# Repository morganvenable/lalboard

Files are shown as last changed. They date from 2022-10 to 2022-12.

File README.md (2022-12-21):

##### lalboard - A 3D-printed keyboard inspired by the DataHand.



## Links

[More Images](https://github.com/JesusFreke/lalboard/wiki/Images)

[120 WPM Typing Demo](https://www.youtube.com/watch?v=oMhOIgrdeE0)

[V2 Project Logs (hackaday.io)](http://lalboard.com)

Online viewer for cluster assemblies:

- [finger](https://a360.co/3vxlLLL)
- [left thumb](https://a360.co/3c63TzE)
- [right thumb](https://a360.co/3c6tvws)

## Project Details

I am a long-time user of a DataHand keyboard. With the scarcity and rising cost of second hand
DataHands these days, I wanted to ensure that I always had access to a DataHand-like keyboard. And
so this project was born.

The overall functionality of the lalboard is obviously heavily based on the DataHand, but I designed
all of the specific key mechanisms, etc. from scratch, to be printable on a normal hobby-level
FDM printer.

With my DataHand, I never felt like I could get the keys positioned *quite right* for my hand. So
one of my primary focuses with the lalboard was adjustability. Each key cluster can be independently
adjusted in all 6 degrees of freedom to some extent.

Most parts need to be printed in a very opaque PLA, but there are a few parts that don't work well
in PLA which should be printed in polycarbonate or similar material, for its strength and heat
resistance.

##### Key Mechanisms

All keys use a pair of magnets to provide the clickiness and key return force, and an IR LED and
phototransistor for detecting a keypress. They are all held in place only with magnets, so they
are easily removable for cleaning, etc.

The feel/clickiness of the keys was another focus area. I tried to get them to feel as similar to
those on a DataHand as possible. They require roughly the same amount of force, and have that same
unique clicky feel due to the magnetic holding force.

##### Adjustability

The key clusters have a trio of standoffs that are designed to be mounted onto a steel sheet with
magnets. Each standoff has an adjustable height, and is mounted to the key cluster via a
ball socket. This provides a limited 6 degrees of freedom in adjusting the angle and position of
each key cluster, in order to get it perfectly positioned for your hands.

##### Fit

Fit is hard and individual.  Additionally, if you're not already a DH user, you'll be adjusting to the new mechanism, layout and typing style, too.  Doing all of this simultaneously can lead to overly fussy adjustment -- sometimes you just have to settle in.

Recommendations for fit:
Your hand should feel relaxed, and your palms should be supported beneath the center of the palm beneath the middle finger, at the minimum.  A palmrest that is too wide will cause discomfort in the outside of the hand, as the base of the pinky really wants to be able to curl around the palmrest a bit.

The palmrests should feel a little crazy tall compared to any other keyboard -- the motions are so small that you can get way more support from the palmrests on a lalboard/datahand.  That said, there are users who use the DH without palmrests at all, so it's a matter of experimentation and preference.  Start with rests, for sure because the relaxation of your hands from the high force, big motion world of traditional keyboards will take some time.

Finger position should be gently curved, maybe 45 degrees from vertical on the final knuckle to the keys -- too much curvature will cause a feeling of being cramped, with many unintentional N keypresses.  Too little will make you strain to hit the N keys.  You want to be able to relax and let your fingers extend naturally.

##### Electronics

As of V2, the lalboard uses standard PCBAs with a mix of SMT and through hole components.  The LEDs and phototransistors (PTs) are vertically mounted and side-firing, so they need to be soldered carefully to ensure they fit into the cluster body.  Once they are installed, there is little need for any additional fasteners, although a clamping screw hole is included in the design.

Each side of the keyboard uses an ESP32S2 MCU, and either can function as the USB connection to the PC.
The connections between the keys are 7 conductor JST cables which can be purchased directly on Amazon, and work fine.  If you want to make your own with nice silicone wires you can (see V1 readme), but the off-the-shelf ones do okay.

The halves are built flashed individually with separate Left and Right FW images that must each be built separately with a special command.
Noted here for convenience (assuming your device is on /dev/ttyACM0)
`SIDE=left idf.py -p /dev/ttyACM0 flash`
`SIDE=right idf.py -p /dev/ttyACM0 flash`
"SIDE" is an environment variable passed to the build system.

##### Handrest

The handrest was first molded for my wrist in plasticine clay, and then scanned in using the
[meshroom](https://github.com/alicevision/meshroom) photogrammetry software. Since they were molded
for my wrists specifically, I'm not sure how "one-size-fits-all" they are, or how comfortable they
would be for someone else to use.

##### [BOM](https://github.com/JesusFreke/lalboard/wiki/BOM)

##### [Printing tips & instructions](https://github.com/JesusFreke/lalboard/wiki/Printing-tips-&-instructions)

--------

Note: This is not an officially supported Google product.

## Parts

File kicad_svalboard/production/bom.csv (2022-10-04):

Designator | Footprint | Quantity | Value | LCSC Part #
C4 | C_0805_2012Metric_Pad1.15x1.40mm_HandSolder | 1 | .1u | C28233
J1 | JST_ZH_B7B-ZR_1x07_P1.50mm_Vertical | 1 | Conn_01x07 | C157978
J3 | JST_ZH_B7B-ZR_1x07_P1.50mm_Vertical | 1 | Conn_01x07 | C157978
J4 | JST_ZH_B7B-ZR_1x07_P1.50mm_Vertical | 1 | Conn_01x07 | C157978
J5 | JST_ZH_B7B-ZR_1x07_P1.50mm_Vertical | 1 | Conn_01x07 | C157978
J2 | JST_ZH_B7B-ZR_1x07_P1.50mm_Vertical | 1 | Conn_01x07 | C157978
J8 | JST_ZH_B7B-ZR_1x07_P1.50mm_Vertical | 1 | Conn_01x07 | C157978
D1 | LED_0805_2012Metric_Pad1.15x1.40mm_HandSolder | 1 | LED | C2297
H1 | MountingHole_3.2mm_M3_DIN965_Pad | 1 | MountingHole_Pad
H2 | MountingHole_3.2mm_M3_DIN965_Pad | 1 | MountingHole_Pad
J6 | PJ-320D | 1 | PJ-320D | C521460
U1 | ProMicro_v3.5 | 1 | ProMicro | C2874015
R11 | R_0805_2012Metric_Pad1.15x1.40mm_HandSolder | 1 | 1.5k | C4310
R12 | R_0805_2012Metric_Pad1.15x1.40mm_HandSolder | 1 | 1.5k | C4310
R13 | R_0805_2012Metric_Pad1.15x1.40mm_HandSolder | 1 | 1.5k | C4310
R10 | R_0805_2012Metric_Pad1.15x1.40mm_HandSolder | 1 | 1.5k | C4310
R14 | R_0805_2012Metric_Pad1.15x1.40mm_HandSolder | 1 | 1.5k | C4310
R3 | R_0805_2012Metric_Pad1.15x1.40mm_HandSolder | 1 | 100k | C149504
R5 | R_0805_2012Metric_Pad1.15x1.40mm_HandSolder | 1 | 2k | C17604
R8 | R_0805_2012Metric_Pad1.15x1.40mm_HandSolder | 1 | 2k | C17604
R7 | R_0805_2012Metric_Pad1.15x1.40mm_HandSolder | 1 | 2k | C17604
R9 | R_0805_2012Metric_Pad1.15x1.40mm_HandSolder | 1 | 2k | C17604
R6 | R_0805_2012Metric_Pad1.15x1.40mm_HandSolder | 1 | 2k | C17604
R4 | R_0805_2012Metric_Pad1.15x1.40mm_HandSolder | 1 | 390k | C17656
R1 | R_0805_2012Metric_Pad1.20x1.40mm_HandSolder | 1 | 5k | C352178
Q6 | SOT-23_Handsoldering | 1 | Q_NMOS_GSD | C5122029
Q4 | SOT-23_Handsoldering | 1 | Q_NPN_BEC | C23869
Q5 | SOT-23_Handsoldering | 1 | Q_NPN_BEC | C23869
Q1 | SOT-23_Handsoldering | 1 | Q_NPN_BEC | C23869
Q3 | SOT-23_Handsoldering | 1 | Q_NPN_BEC | C23869
Q2 | SOT-23_Handsoldering | 1 | Q_NPN_BEC | C23869
SW2 | SW_PUSH_6mm_H5mm | 1 | Boot | C428628
SW1 | SW_PUSH_6mm_H5mm | 1 | Reset | C428628
U5 | TSSOP-14_4.4x5mm_P0.65mm | 1 | LMV324 | C398929
U6 | TSSOP-14_4.4x5mm_P0.65mm | 1 | LMV324 | C398929

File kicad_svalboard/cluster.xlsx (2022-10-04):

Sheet: cluster
Source: | C:\Users\morga\Documents\GitHub\lalboard\kicad\cluster.sch
Date: | 2022-08-30 10:52
Tool: | Eeschema (6.0.7)
Generator: | C:\Program Files\KiCad\6.0\bin\scripting\plugins/bom_csv_grouped_by_value_with_fp.py
Component Count: | 16
Ref | Qnty | Value | Cmp name | Footprint | Description | Vendor
IR1, IR2, IR3, IR4, IR5, | 5 | IR908-7C-F | IR908-7C-F | lalboard:IR908-7C-F | 940nm Sidelooker IR LED
J1, | 1 | Conn_01x07 | Conn_01x07 | lalboard:JST_ZH_S7B-ZR_1x07_P1.50mm_Horizontal | Generic connector, single row, 01x07, script generated (kicad-library-utils/schlib/autogen/connector/)
PT1, PT2, PT3, PT4, PT5, | 5 | PT908-7B-F | PT908-7B-F | lalboard:PT908-7C-F | 940nm Sidelooker Phototransistor
R1, R2, R3, R4, R5, | 5 | 270 | R | Resistor_SMD:R_1206_3216Metric_Pad1.42x1.75mm_HandSolder | Resistor

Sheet: main_board
Source: | C:\Users\morga\Documents\GitHub\lalboard\kicad\main_board.sch
Date: | 2022-08-30 10:51
Tool: | Eeschema (6.0.7)
Generator: | C:\Program Files\KiCad\6.0\bin\scripting\plugins/bom_csv_grouped_by_value_with_fp.py
Component Count: | 56
Ref | Qnty | Value | Cmp name | Footprint | Description | Vendor
C1, C6, | 2 | 10u | C_Small | Capacitor_SMD:C_0805_2012Metric_Pad1.15x1.40mm_HandSolder | Unpolarized capacitor, small symbol
C2, C4, C5, C8, C9, | 5 | .1u | C_Small | Capacitor_SMD:C_0805_2012Metric_Pad1.15x1.40mm_HandSolder | Unpolarized capacitor, small symbol
C3, | 1 | 1u | C_Small | Capacitor_SMD:C_0805_2012Metric_Pad1.15x1.40mm_HandSolder | Unpolarized capacitor, small symbol
C7, | 1 | 4.7u | C_Small | Capacitor_SMD:C_0805_2012Metric_Pad1.15x1.40mm_HandSolder | Unpolarized capacitor, small symbol
FB1, FB2, FB3, FB4, | 4 | ACML-0805-500-T | Ferrite_Bead_Small-Device | Inductor_SMD:L_0805_2012Metric_Pad1.15x1.40mm_HandSolder
H1, H2, | 2 | MountingHole_Pad | MountingHole_Pad | MountingHole:MountingHole_3.2mm_M3_DIN965_Pad | Mounting Hole with connection
J1, J2, J3, J4, J5, J8, | 6 | Conn_01x07 | Conn_01x07 | lalboard:JST_ZH_B7B-ZR_1x07_P1.50mm_Vertical | Generic connector, single row, 01x07, script generated (kicad-library-utils/schlib/autogen/connector/)
J6, J7, | 2 | TYPE-C-31-M-12 | USB_C_Receptacle_USB2.0-Connector | Connector_USB:USB_C_Receptacle_HRO_TYPE-C-31-M-12
Q1, Q2, Q3, Q4, Q5, | 5 | Q_NPN_BEC | Q_NPN_BEC | Package_TO_SOT_SMD:SOT-23_Handsoldering | NPN transistor, base/emitter/collector
R1, R2, | 2 | 10k | R_Small | Resistor_SMD:R_0805_2012Metric_Pad1.15x1.40mm_HandSolder | Resistor, small symbol
R3, | 1 | 100k | R_Small | Resistor_SMD:R_0805_2012Metric_Pad1.15x1.40mm_HandSolder | Resistor, small symbol
R4, | 1 | 390k | R_Small | Resistor_SMD:R_0805_2012Metric_Pad1.15x1.40mm_HandSolder | Resistor, small symbol
R5, R6, R7, R8, R9, | 5 | 2k | R_Small | Resistor_SMD:R_0805_2012Metric_Pad1.15x1.40mm_HandSolder | Resistor, small symbol
R10, R11, R12, R13, R14, | 5 | 1.5k | R | Resistor_SMD:R_0805_2012Metric_Pad1.15x1.40mm_HandSolder | Resistor
R15, R16, R17, R18, | 4 | 5.1k | R_Small | Resistor_SMD:R_0805_2012Metric_Pad1.15x1.40mm_HandSolder | Resistor, small symbol
R19, R20, | 2 | 22 | R_Small | Resistor_SMD:R_0805_2012Metric_Pad1.15x1.40mm_HandSolder | Resistor, small symbol
SW1, | 1 | Reset | SW_Push | Button_Switch_THT:SW_PUSH_6mm_H5mm | Push button switch, generic, two pins
SW2, | 1 | Boot | SW_Push | Button_Switch_THT:SW_PUSH_6mm_H5mm | Push button switch, generic, two pins
U1, | 1 | esp32-s2-wroom | esp32-s2-wroom | lalboard:ESP32-S2-WROOM-handsoldering
U2, | 1 | XC6220B331MR | XC6220B331MR | Package_TO_SOT_SMD:SOT-23-5 | 1A, Low Drop-out Voltage Regulator, Fixed Output 3.3V, SOT-23-5
U3, U4, | 2 | USBLC6-2SC6 | USBLC6-2SC6 | Package_TO_SOT_SMD:SOT-23-6 | Very low capacitance ESD protection diode, 2 data-line, SOT-23-6
U5, U6, | 2 | LMV324 | LMV324 | lalboard:TSSOP-14_4.4x5mm_P0.65mm | Quad Low-Voltage Rail-to-Rail Output Operational Amplifier, SOIC-14/SSOP-14

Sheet: thumb_cluster_left
Source: | C:\Users\morga\Documents\GitHub\lalboard\kicad\thumb_cluster_left.kicad_sch
Date: | 2022-08-30 10:53
Tool: | Eeschema (6.0.7)
Generator: | C:\Program Files\KiCad\6.0\bin\scripting\plugins/bom_csv_grouped_by_value_with_fp.py
Component Count: | 18
Ref | Qnty | Value | Cmp name | Footprint | Description | Vendor
H1, H2, | 2 | MountingHole_Pad | MountingHole_Pad | MountingHole:MountingHole_3.2mm_M3_Pad | Mounting Hole with connection
IR1, IR2, IR3, IR4, IR5, | 5 | IR908-7C-F | IR908-7C-F | lalboard:IR908-7C-F | 940nm Sidelooker IR LED
J1, | 1 | Conn_01x07 | Conn_01x07 | lalboard:JST_ZH_B7B-ZR_1x07_P1.50mm_Vertical | Generic connector, single row, 01x07, script generated (kicad-library-utils/schlib/autogen/connector/)
PT1, PT2, PT3, PT4, PT5, | 5 | PT908-7B-F | PT908-7B-F | lalboard:PT908-7C-F | 940nm Sidelooker Phototransistor
R1, | 1 | 56 | R | Resistor_SMD:R_1206_3216Metric_Pad1.42x1.75mm_HandSolder | Resistor
R2, | 1 | 100 | R | Resistor_SMD:R_1206_3216Metric_Pad1.42x1.75mm_HandSolder | Resistor
R3, | 1 | 120 | R | Resistor_SMD:R_1206_3216Metric_Pad1.42x1.75mm_HandSolder | Resistor
R4, | 1 | 180 | R | Resistor_SMD:R_1206_3216Metric_Pad1.42x1.75mm_HandSolder | Resistor
R5, | 1 | 150 | R | Resistor_SMD:R_1206_3216Metric_Pad1.42x1.75mm_HandSolder | Resistor

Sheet: thumb_cluster_right
Source: | C:\Users\morga\Documents\GitHub\lalboard\kicad\thumb_cluster_right.kicad_sch
Date: | 2022-08-30 10:54
Tool: | Eeschema (6.0.7)
Generator: | C:\Program Files\KiCad\6.0\bin\scripting\plugins/bom_csv_grouped_by_value_with_fp.py
Component Count: | 18
Ref | Qnty | Value | Cmp name | Footprint | Description | Vendor
H1, H2, | 2 | MountingHole_Pad | MountingHole_Pad | MountingHole:MountingHole_3.2mm_M3_Pad | Mounting Hole with connection
IR1, IR2, IR3, IR4, IR5, | 5 | IR908-7C-F | IR908-7C-F | lalboard:IR908-7C-F | 940nm Sidelooker IR LED
J1, | 1 | Conn_01x07 | Conn_01x07 | lalboard:JST_ZH_B7B-ZR_1x07_P1.50mm_Vertical | Generic connector, single row, 01x07, script generated (kicad-library-utils/schlib/autogen/connector/)
PT1, PT2, PT3, PT4, PT5, | 5 | PT908-7B-F | PT908-7B-F | lalboard:PT908-7C-F | 940nm Sidelooker Phototransistor
R1, | 1 | 56 | R | Resistor_SMD:R_1206_3216Metric_Pad1.42x1.75mm_HandSolder | Resistor
R2, | 1 | 100 | R | Resistor_SMD:R_1206_3216Metric_Pad1.42x1.75mm_HandSolder | Resistor
R3, | 1 | 120 | R | Resistor_SMD:R_1206_3216Metric_Pad1.42x1.75mm_HandSolder | Resistor
R4, | 1 | 180 | R | Resistor_SMD:R_1206_3216Metric_Pad1.42x1.75mm_HandSolder | Resistor
R5, | 1 | 150 | R | Resistor_SMD:R_1206_3216Metric_Pad1.42x1.75mm_HandSolder | Resistor

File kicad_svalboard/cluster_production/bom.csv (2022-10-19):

Designator | Footprint | Quantity | Value | LCSC Part #
J1 | FH34SRJ8S05SH50 | 1 | Conn_01x07
Q2 | PT12-21B | 1 | PT12-21B | C264383
Q5 | PT12-21B | 1 | PT12-21B | C264383
D3 | IR12-21C | 1 | IR12-21C | C53672
D1 | IR12-21C | 1 | IR12-21C | C53672
Q4 | PT12-21B | 1 | PT12-21B | C264383
D4 | IR12-21C | 1 | IR12-21C | C53672
Q3 | PT12-21B | 1 | PT12-21B | C264383
Q1 | PT12-21B | 1 | PT12-21B | C264383
D5 | IR12-21C | 1 | IR12-21C | C53672
D2 | IR12-21C | 1 | IR12-21C | C53672
R5 | R_0805_2012Metric_Pad1.20x1.40mm_HandSolder | 1 | 270
R2 | R_0805_2012Metric_Pad1.20x1.40mm_HandSolder | 1 | 270
R1 | R_0805_2012Metric_Pad1.20x1.40mm_HandSolder | 1 | 270
R4 | R_0805_2012Metric_Pad1.20x1.40mm_HandSolder | 1 | 270
R3 | R_0805_2012Metric_Pad1.20x1.40mm_HandSolder | 1 | 270

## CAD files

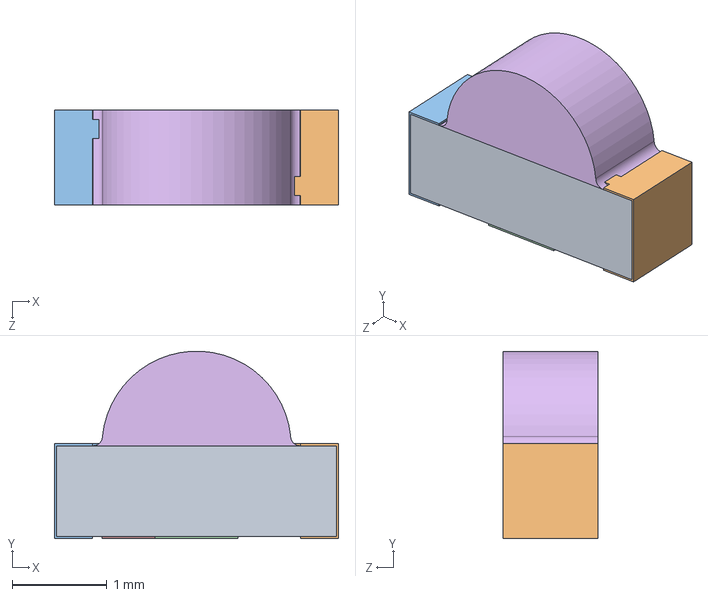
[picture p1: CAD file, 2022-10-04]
kicad_svalboard/datasheets/EAISS3010A1/3010STEP.STEP
3.00 x 1.98 x 1.00 mm

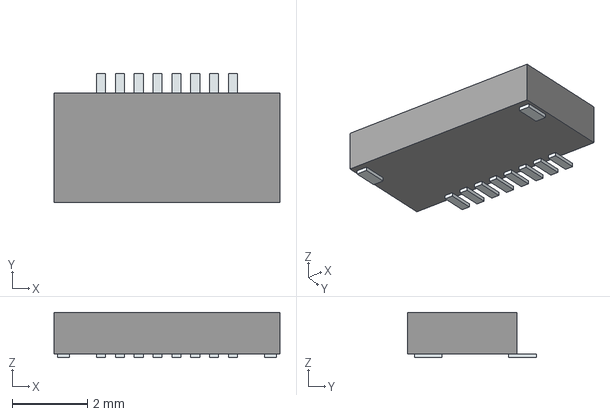
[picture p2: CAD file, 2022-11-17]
kicad_svalboard/datasheets/LIB_FH34SRJ-8S-0.5SH_50_/FH34SRJ-8S-0.5SH_50_/3D/FH34SRJ-8S-0.5SH_50_.stp
6.00 x 3.42 x 1.20 mm
Pins

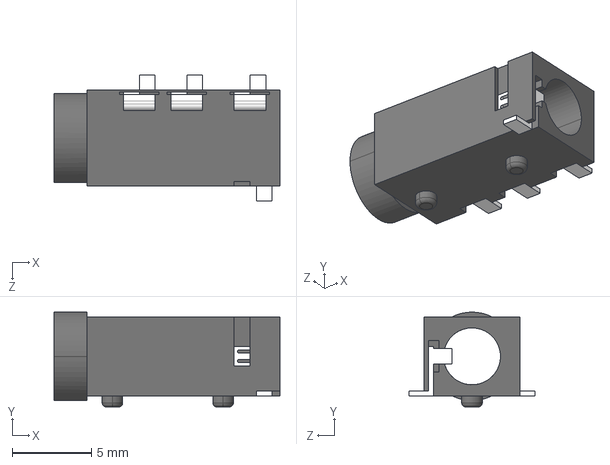
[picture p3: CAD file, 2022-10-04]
kicad_svalboard/datasheets/PJ-320D/3D/PJ-320D.stp
14.3 x 6.00 x 8.00 mm

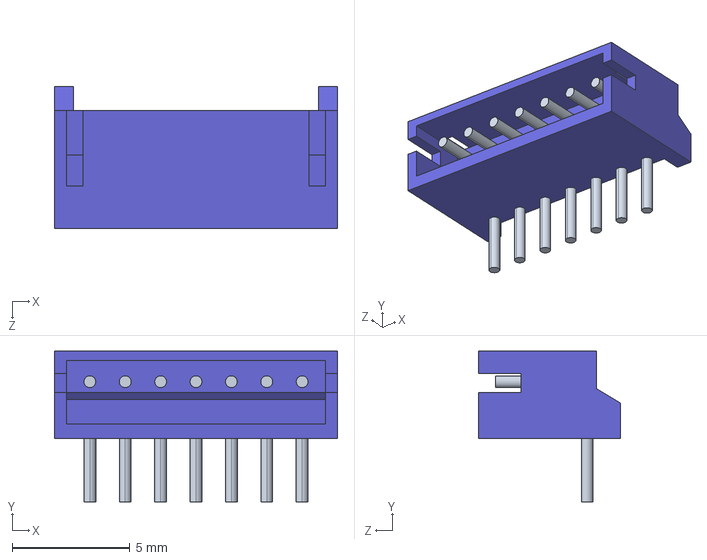
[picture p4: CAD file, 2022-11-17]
kicad_svalboard/datasheets/S7B-ZR.IGS
12.0 x 6.40 x 6.00 mm

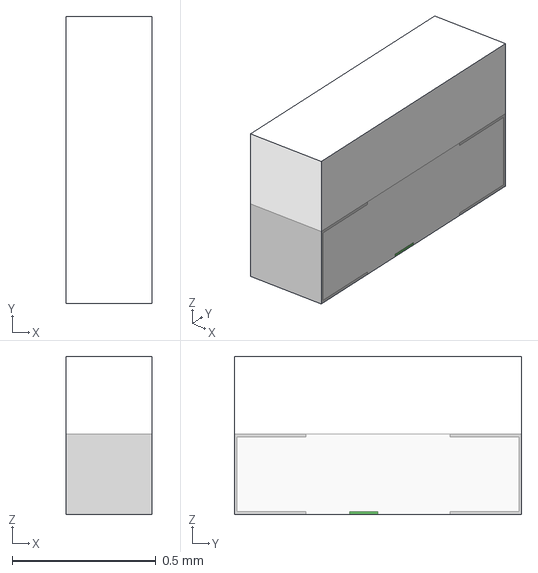
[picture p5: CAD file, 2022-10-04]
kicad_svalboard/datasheets/WE_15404085BA470_Libraries/Download_IGS_WL-SISW_0402 (rev1).igs
0.3 x 1.00 x 0.55 mm

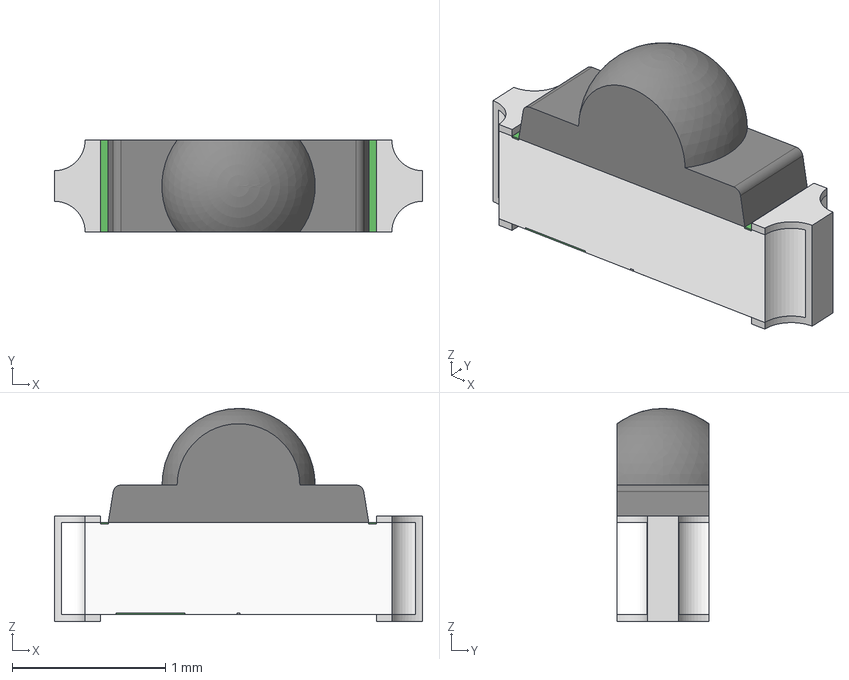
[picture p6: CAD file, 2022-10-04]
kicad_svalboard/datasheets/WE_1541021NCA170_Libraries/Download_STEP_1541021NCA170 (rev1).stp
2.40 x 0.6 x 1.39 mm
Pins
Dome

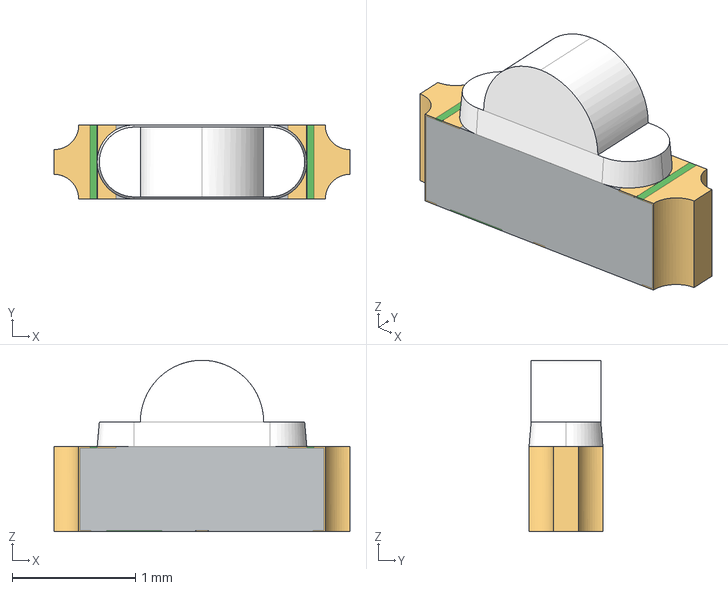
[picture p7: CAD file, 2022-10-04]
kicad_svalboard/datasheets/WE_15410294AA570_Libraries/Download_IGS_WL-SISW_1002 (rev1).igs
2.40 x 0.6 x 1.39 mm

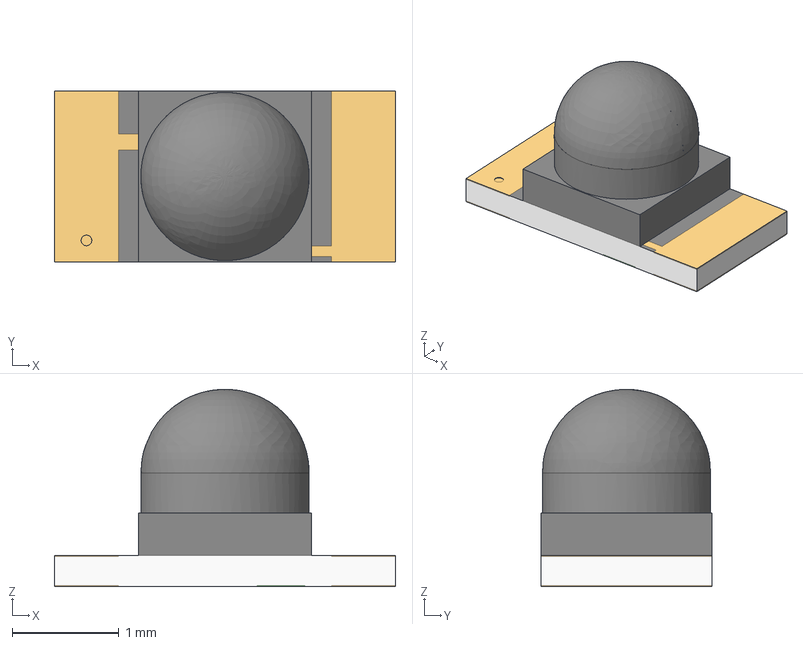
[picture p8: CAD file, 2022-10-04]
kicad_svalboard/datasheets/WE_1541201NC3060_Libraries/Download_IGS_1541201NC3060 (rev1).igs
3.20 x 1.60 x 1.85 mm

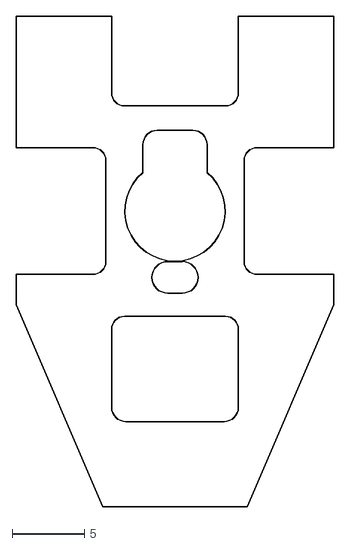
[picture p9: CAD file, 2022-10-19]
kicad_svalboard/SvalboardPCBOutlineV7.dxf
22.0 x 34.0

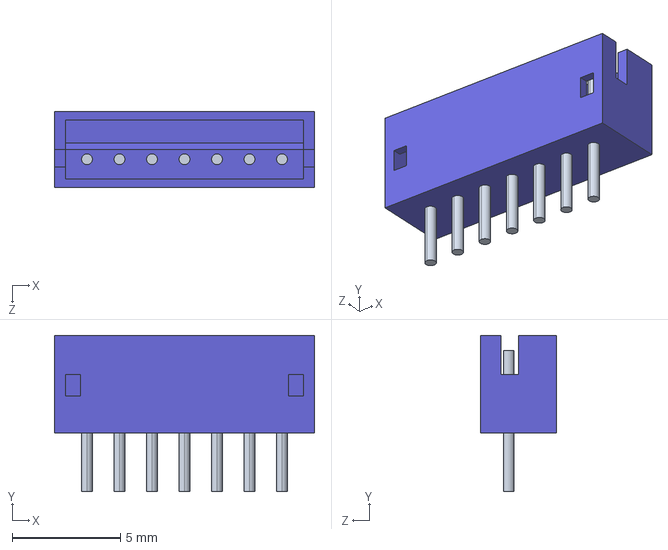
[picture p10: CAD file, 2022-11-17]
kicad_svalboard/datasheets/B7B-ZR.IGS
12.0 x 7.20 x 3.50 mm

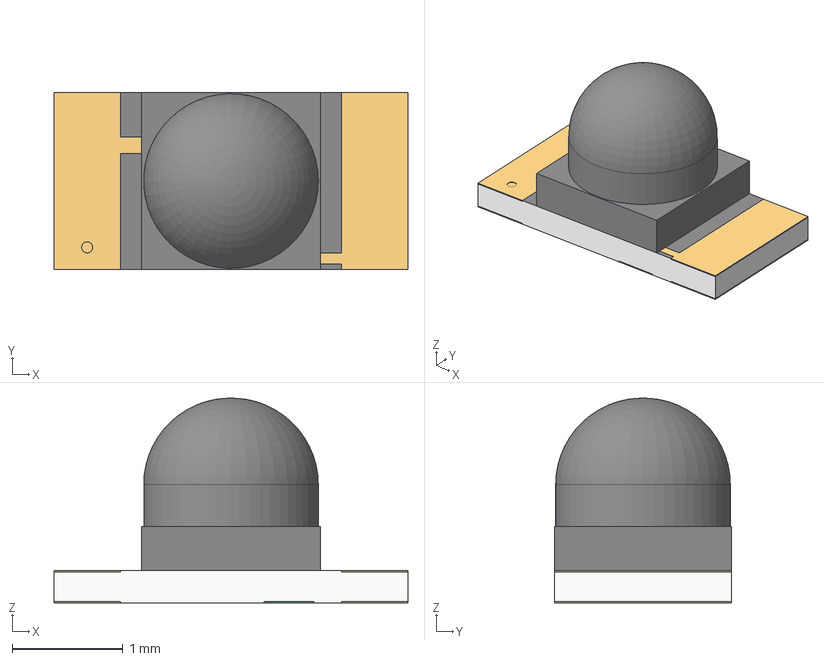
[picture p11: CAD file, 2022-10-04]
kicad_svalboard/datasheets/WE_1541201NC3060_Libraries/Download_STP_1541201NC3060 (rev1).stp
3.20 x 1.60 x 1.85 mm
PCB
Pins
Resin

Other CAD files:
kicad_svalboard/datasheets/WE_15404085BA470_Libraries/Download_STP_WL-SISW_0402 (rev1).stp
kicad_svalboard/datasheets/WE_1541021NCA170_Libraries/Download_IGS_1541021NCA170 (rev1).igs
kicad_svalboard/datasheets/WE_15410294AA570_Libraries/Download_STP_WL-SISW_1002 (rev1).stp
kicad_svalboard/datasheets/LIB_FH34SRJ-8S-0.5SH_50_/FH34SRJ-8S-0.5SH_50_/Allegro/fh34srj8s05sh50.psm
kicad_svalboard/datasheets/LIB_FH34SRJ-8S-0.5SH_50_/FH34SRJ-8S-0.5SH_50_/DEHDL/fh34srj_8s_0.5sh_50_/chips/chips.prt
kicad_svalboard/datasheets/PJ-320D/Allegro/pj320d.psm
kicad_svalboard/datasheets/PJ-320D/DEHDL/pj_320d/chips/chips.prt

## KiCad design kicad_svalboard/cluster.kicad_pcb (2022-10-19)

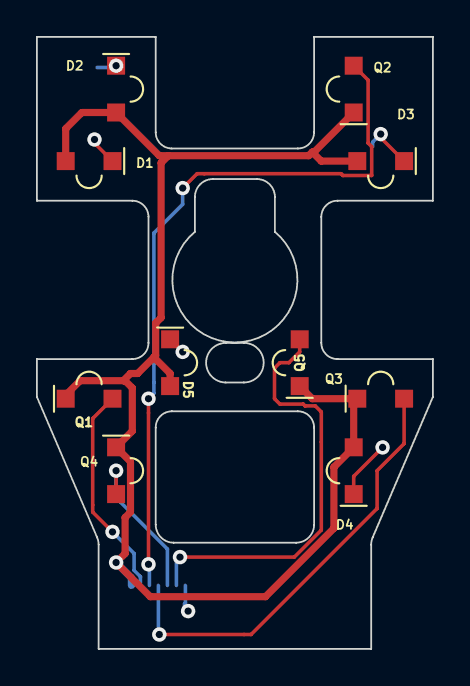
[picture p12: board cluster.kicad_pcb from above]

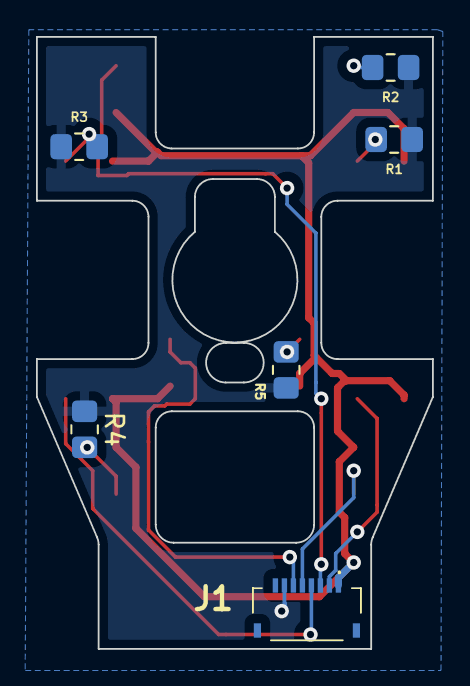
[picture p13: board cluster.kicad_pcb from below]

Board: 2 copper layers, 22.0 x 34.0 mm, 16 parts (6 on the bottom side), 12 nets.

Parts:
D1, D2, D3, D4, D5: IR12-21C
J1: Conn_01x07; FH34SRJ8S05SH50
Q1, Q2, Q3, Q4, Q5: PT12-21B
R1, R2, R3, R4, R5: 270; R_0805_2012Metric_Pad1.20x1.40mm_HandSolder

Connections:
+5V: D1.1 (K), D2.1 (K), D3.1 (K), D4.1 (K), D5.1 (K), J1.1, Q1.1 (C), Q2.1 (C), Q3.1 (C), Q4.1 (C), Q5.1 (C)
C1: J1.2, Q1.2 (E)
C2: J1.3, Q2.2 (E)
C3: J1.4, Q3.2 (E)
C4: J1.5, Q4.2 (E)
C5: J1.6, Q5.2 (E)
GND: J1.7, R1.1, R2.1, R3.1, R4.1, R5.1
unnamed: D1.2 (A), R1.2
unnamed: D2.2 (A), R2.2
unnamed: D3.2 (A), R3.2
unnamed: D4.2 (A), R4.2
unnamed: D5.2 (A), R5.2

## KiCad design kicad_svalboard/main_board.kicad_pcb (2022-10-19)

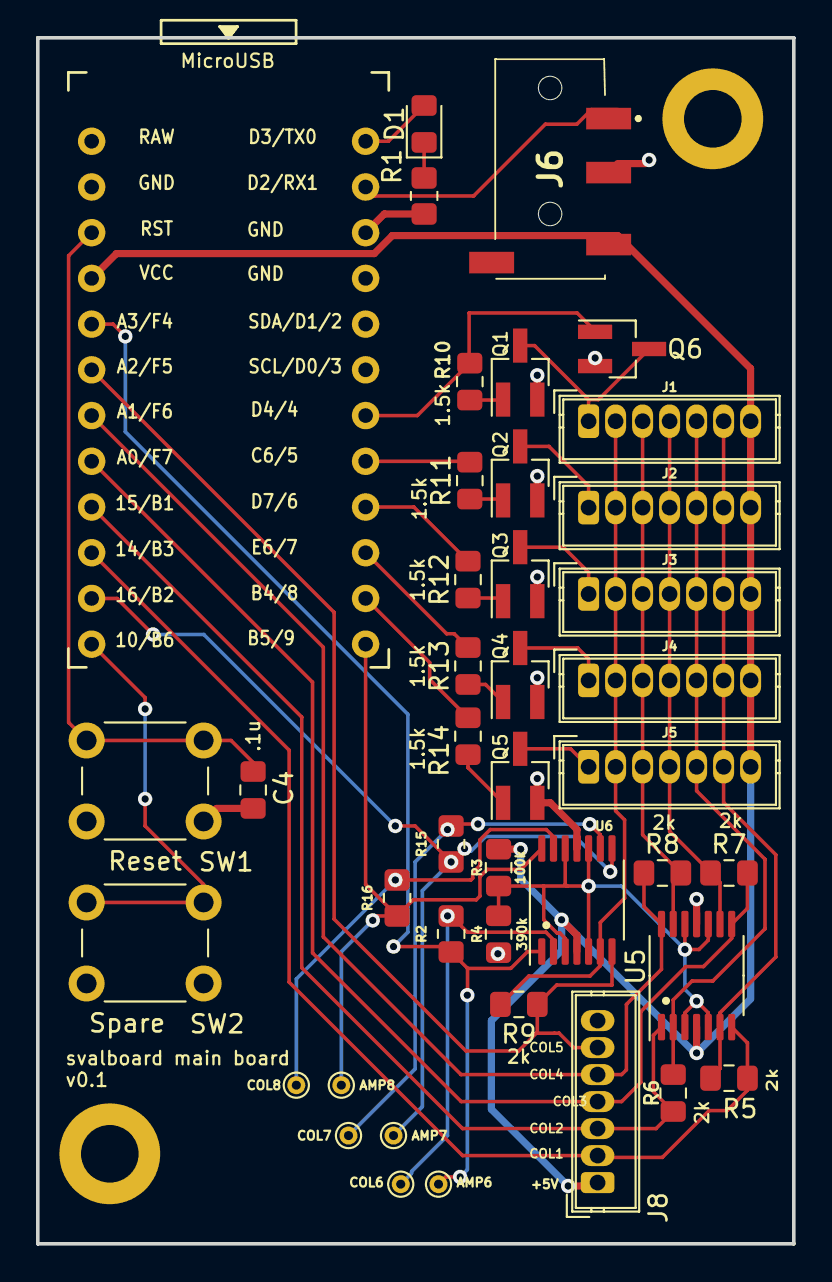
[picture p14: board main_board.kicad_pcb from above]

Board: 2 copper layers, 42.0 x 67.0 mm, 44 parts (0 on the bottom side), 39 nets.

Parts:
AMP6, AMP7, AMP8: TestPoint; TestPoint_THTPad_D1.0mm_Drill0.5mm
C4: .1u; C_0805_2012Metric_Pad1.15x1.40mm_HandSolder
COL6, COL7, COL8: TestPoint; TestPoint_THTPad_D1.0mm_Drill0.5mm
D1: LED; LED_0805_2012Metric_Pad1.15x1.40mm_HandSolder
H1, H2: MountingHole_Pad; MountingHole_3.2mm_M3_DIN965_Pad
J1, J2, J3, J4, J5, J8: Conn_01x07; JST_ZH_B7B-ZR_1x07_P1.50mm_Vertical
J6: PJ-320D
Q1, Q2, Q3, Q4, Q5: Q_NPN_BEC; SOT-23_Handsoldering
Q6: Q_NMOS_GSD; SOT-23_Handsoldering
R1: 5k; R_0805_2012Metric_Pad1.20x1.40mm_HandSolder
R2, R15, R16: 2k; R_0805_2012Metric_Pad1.20x1.40mm_HandSolder
R3: 100k; R_0805_2012Metric_Pad1.15x1.40mm_HandSolder
R4: 390k; R_0805_2012Metric_Pad1.15x1.40mm_HandSolder
R5, R6, R7, R8, R9: 2k; R_0805_2012Metric_Pad1.15x1.40mm_HandSolder
R10, R11, R12, R13, R14: 1.5k; R_0805_2012Metric_Pad1.15x1.40mm_HandSolder
SW1: Reset; SW_PUSH_6mm_H5mm
SW2: Spare; SW_PUSH_6mm_H5mm
U1: ProMicro; ProMicro_v3.5
U5, U6: LMV324; TSSOP-14_4.4x5mm_P0.65mm

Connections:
+5V: J1.7, J2.7, J3.7, J4.7, J5.7, J6.4, J8.1, R3.1, U1.21 (VCC), U5.4 (V+), U6.4 (V+)
/AMP_REF: R3.2, R4.1, U5.3 (+), U5.5 (+), U5.10 (+), U5.12 (+), U6.3 (+), U6.5 (+), U6.10 (+), U6.12 (+)
/COL1: J1.6, J2.6, J3.6, J4.6, J5.6, R5.2, U5.6 (-)
/COL1_AMP: J8.2, R5.1, U1.15 (B3), U5.7
/COL2: J1.5, J2.5, J3.5, J4.5, J5.5, R6.2, U5.2 (-)
/COL2_AMP: J8.3, R6.1, U1.16 (B1), U5.1
/COL3: J1.4, J2.4, J3.4, J4.4, J5.4, R7.2, U5.9 (-)
/COL3_AMP: J8.4, R7.1, U1.17 (F7), U5.8
/COL4: J1.3, J2.3, J3.3, J4.3, J5.3, R8.2, U5.13 (-)
/COL4_AMP: J8.5, R8.1, U1.18 (F6), U5.14
/COL5: J1.2, J2.2, J3.2, J4.2, J5.2, R9.2, U6.6 (-)
/COL5_AMP: J8.6, R9.1, U1.19 (F5), U6.7
/COL6: COL6.1, R2.2, U6.2 (-)
/COL6_AMP: AMP6.1, R2.1, U1.20 (F4), U6.1
/COL7: COL7.1, R15.2, U6.9 (-)
/COL7_AMP: AMP7.1, R15.1, U1.14 (B2), U6.8
/COL8: COL8.1, R16.2, U6.13 (-)
/COL8_AMP: AMP8.1, R16.1, U1.12 (B5), U6.14
/DATA: J6.2, U1.2 (RX)
/LED: D1.2 (A), U1.1 (TX)
/RESET: C4.2, SW1.1, U1.22 (RST)
/ROW1: R14.2, U1.11 (B4)
/ROW2: R13.2, U1.10 (E6)
/ROW3: R12.2, U1.9 (D7)
/ROW4: R11.2, U1.8 (C6)
/ROW5: Q6.1 (G), R10.2, U1.7 (D4)
/SPARE: SW2.1, U1.13 (B6)
GND: C4.1, H1.1, H2.1, J6.3, J8.7, Q1.2 (E), Q2.2 (E), Q3.2 (E), Q4.2 (E), Q5.2 (E), Q6.2 (S), R1.2, R4.2, SW1.2, SW2.2, U1.3 (GND), U1.4 (GND), U1.23 (GND), U5.11 (V-), U6.11 (V-)
unnamed: D1.1 (K), R1.1
unnamed: J1.1, Q1.3 (C), Q6.3 (D)
unnamed: J2.1, Q2.3 (C)
unnamed: J3.1, Q3.3 (C)
unnamed: J4.1, Q4.3 (C)
unnamed: J5.1, Q5.3 (C)
unnamed: Q1.1 (B), R10.1
unnamed: Q2.1 (B), R11.1
unnamed: Q3.1 (B), R12.1
unnamed: Q4.1 (B), R13.1
unnamed: Q5.1 (B), R14.1

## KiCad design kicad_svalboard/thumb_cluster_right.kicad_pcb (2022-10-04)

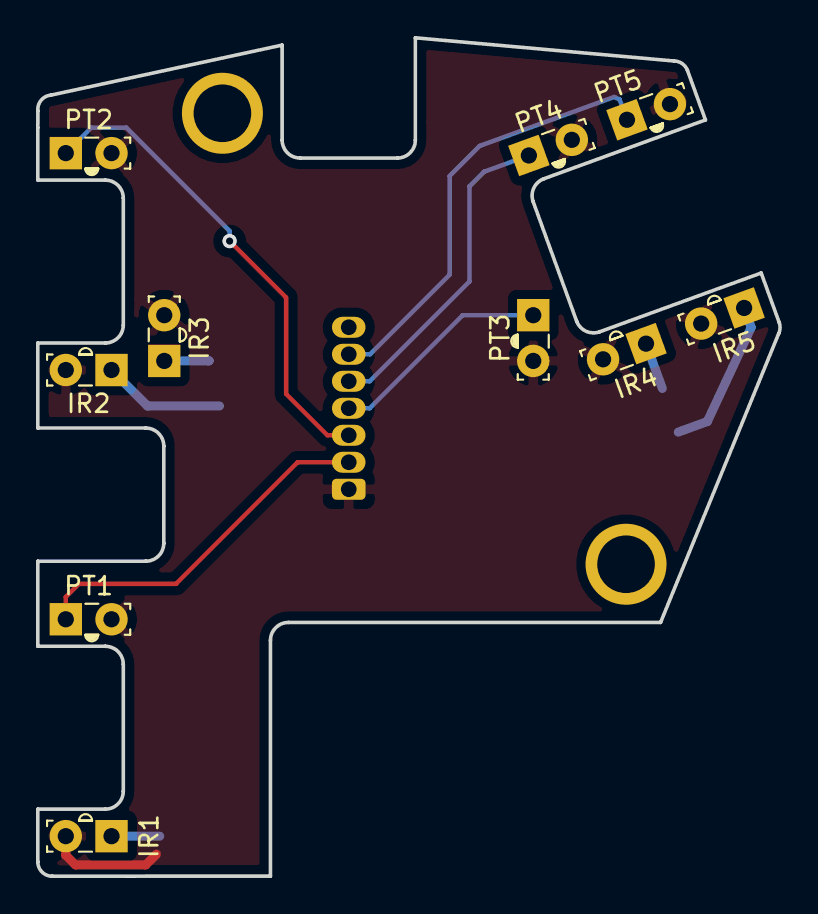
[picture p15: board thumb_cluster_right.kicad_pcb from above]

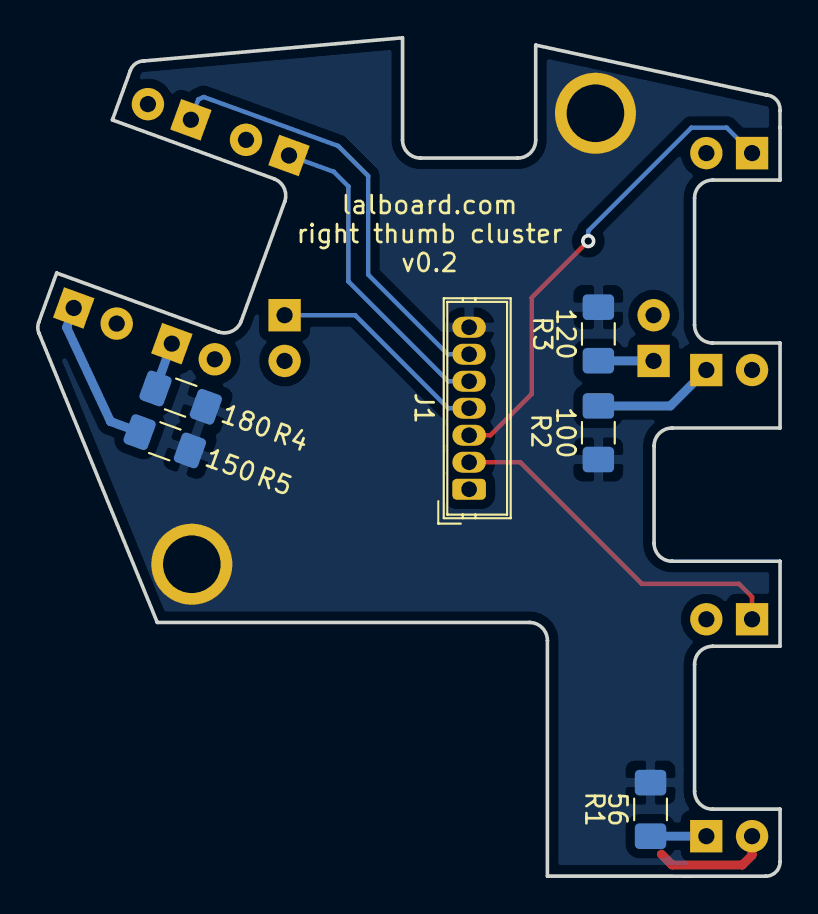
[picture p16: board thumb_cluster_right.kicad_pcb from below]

Board: 2 copper layers, 41.2 x 46.6 mm, 18 parts (6 on the bottom side), 12 nets.

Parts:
H1, H2: MountingHole_Pad; MountingHole_3.2mm_M3_Pad
IR1, IR2, IR3, IR4, IR5: IR908-7C-F
J1: Conn_01x07; JST_ZH_B7B-ZR_1x07_P1.50mm_Vertical
PT1, PT2, PT3, PT4, PT5: PT908-7B-F; PT908-7C-F
R1: 56; R_1206_3216Metric_Pad1.42x1.75mm_HandSolder
R2: 100; R_1206_3216Metric_Pad1.42x1.75mm_HandSolder
R3: 120; R_1206_3216Metric_Pad1.42x1.75mm_HandSolder
R4: 180; R_1206_3216Metric_Pad1.42x1.75mm_HandSolder
R5: 150; R_1206_3216Metric_Pad1.42x1.75mm_HandSolder

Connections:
+5V: IR1.2, IR2.2, IR3.2, IR4.2, IR5.2, J1.1, PT1.2, PT2.2, PT3.2, PT4.2, PT5.2
C1: J1.2, PT1.1
C2: J1.3, PT2.1
C3: J1.4, PT3.1
C4: J1.5, PT4.1
C5: J1.6, PT5.1
GND: H1.1, H2.1, J1.7, R1.1, R2.1, R3.1, R4.1, R5.1
unnamed: IR1.1, R1.2
unnamed: IR2.1, R2.2
unnamed: IR3.1, R3.2
unnamed: IR4.1, R4.2
unnamed: IR5.1, R5.2

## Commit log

2022-10-04 Bulk backup of Kicad branch.
    [3010STEP.STEP, Download_IGS_1541021NCA170 (rev1).igs, Download_IGS_1541201NC3060 (rev1).igs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]
2022-10-19 Removed datasheets folder, updated design with layouts for cluster and main PCB. still need FFC connectors on main PCB
    [SvalboardPCBOutlineV7.dxf, bom.csv, cluster.kicad_pcb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]
2022-11-17 fixing a mess
    [B7B-ZR.IGS, EDI2CAP.CFG, FH34SRJ-8S-0.5SH_50_.stp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]
